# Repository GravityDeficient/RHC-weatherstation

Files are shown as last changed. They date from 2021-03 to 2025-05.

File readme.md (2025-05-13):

# RHC - Weather Station
An open source self contained weather station for remote applications where wifi and power are not available.

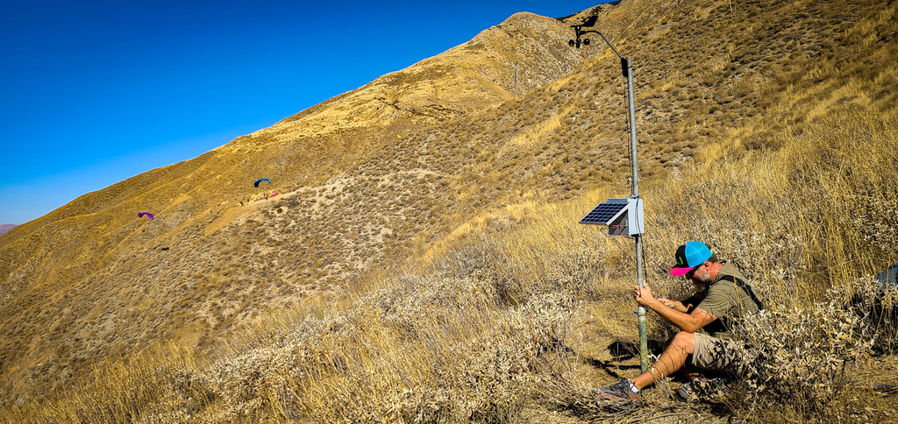
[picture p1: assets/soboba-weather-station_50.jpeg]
Soboba Flight Park Weather Station

### Overview

The weather station is based around the Particle Cloud platform and the latest design uses the Particle.IO Boron LTE CAT-M1 development board for processing and connectivity. 
Additionally a small arduino pro-mini is used as a watchdog to monitor system state and induce a restart if the system is hung. This forces the Particle to reconnect and check in.

Wind observation are taken using a Davis Vantage Pro 6410 anemometer. Temperature, pressure, and humidify can be observed with a BPM280 or BME280 sensor.

Listener software running on a base unit (internet connected Particle Argon) or server application (nodejs) will monitor observations published to particle cloud from the weather station and post the parsed data to Weather Underground and Weather Flow. In the case of the server application we log obervations to a database that serves can be used to generate your own weather graphs without 3rd part services.

- [Recommended BOM](bom.md) 
- [Assembly instructions](assembly.md)
- [RHC-Weatherstation-Listener](https://github.com/GravityDeficient/RHC-Weatherstation-Listener) Reciever applictaion written in NodeJS
- [To-Do](TODO.md)

### Configuration
The weather station uses a simple configuration system that's easy to customize:

1. All configuration settings are in a single file: `config.h`
2. If you're setting up a new installation, copy `config.h.example` to `config.h`
3. Edit the settings in the clearly marked "USER CONFIGURATION" section
4. Make your changes directly in this file - the comments provide guidance on what each setting does
5. Note that `config.h` is in .gitignore, so your custom settings won't be committed

Key settings you might want to customize:
- EVENT_NAME: The name used for publishing data to the Particle Cloud 
- TIMEZONE: Set to your local timezone
- USE_DST: Enable or disable Daylight Saving Time
- CNTS_TO_MPH: Calibration factor for your specific anemometer

Example of the config.h settings:

```c
// Event name for publishing data
// Change this to your own custom event name
#define EVENT_NAME ("my_custom_event")

// Timezone settings
// Modify for your location
#define TIMEZONE (-8)  // Pacific Standard Time

// Daylight Saving Time settings
#define USE_DST (1)    // Enable Daylight Saving Time
#define DST_OFFSET (1) // 1 hour offset for DST

// DST start rule (second Sunday in March for USA)
#define DST_START_MONTH (3)  // March
#define DST_START_WEEK (2)   // Second week
#define DST_START_DOW (0)    // Sunday (0 = Sunday, 1 = Monday, etc.)

// DST end rule (first Sunday in November for USA)
#define DST_END_MONTH (11)   // November
#define DST_END_WEEK (1)     // First week
#define DST_END_DOW (0)      // Sunday

// Wind speed calibration
// Change this for your specific anemometer
#define CNTS_TO_MPH (2.174)  // For Mussel Rock Anemometer
```

After changing the configuration, compile and flash your device to apply the changes.

### Important Notes for Compilation

- **Pro Mini Watchdog**: Before compiling the Boron firmware, you must remove the `station/pro-mini_watchdog.ino` file. This file is for the Arduino Pro Mini watchdog device and should not be included in the Boron compilation.

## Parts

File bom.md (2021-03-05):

### BOM
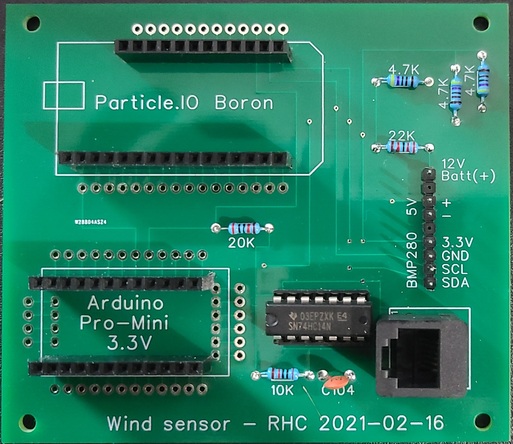
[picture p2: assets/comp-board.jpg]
Assembled Board

#### Hardware Power and Sensors 
1. 20A Solar Charge Controller --[Amazon](https://www.amazon.com/gp/product/B072MMDY4F)
2. ExpertPower 12v 9ah Sealed Lead Acid Battery --[Amazon](https://www.amazon.com/ExpertPower-EXP1290-2-Batteries-BX1300LCD-Replacement/dp/B001NJ3H0C)
3. 10W Solar Panel --[Amazon](https://www.amazon.com/gp/product/B00OZC3X1C/)
4. Cantex 5133712 Electrical Box --[Ebay](https://www.ebay.com/itm/CANTEX-5133712-Electrical-Box-PVC-8-5-8x8-5-8x4-in/383686744477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)
5. Davis Instruments 6410 Anemometer --[Ebay](https://www.ebay.com/itm/Davis-Instruments-6410-Davis-Anemometer-For-Vantage-Pro-Pro2-6152-New/383033311103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)
6. 1/2 NPT Nylon Cable Gland --[Amazon 12pcs](https://www.amazon.com/gp/product/B07ZRH3V59/ref=ppx_yo_dt_b_asin_title_o02_s00?ie=UTF8&psc=1)

##### Optional Sensors
- BMP280 (Preasure, Temperature) --[Amazon](https://www.amazon.com/GY-BMP280-3-3-Precision-Atmospheric-Pressure-Barometric/dp/B087ZRGSC8/)
- BME280 (Pressure, Temperature, Humidity) --[Amazon](https://www.amazon.com/Aideepen-Breakout-Temperature-Precision-Barometric/dp/B07RWCCKJX/)

#### PCB Components
1. Boron LTE CAT-M1 (NorAm) --[Particle.io](https://store.particle.io/products/boron-lte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) 
2. Ardunio Pro-Mini (3.3v) --[Amazon](https://www.amazon.com/gp/product/B01JA58DHM/)
3. PCB
4. 3x 4.7K resisters
5. 1x 22k resister
6. 1x 20k resister
7. 1x 10k resister
8. 1x C104 capacitor (0.1uF Ceramic Capacitor)
9. 1x 74HC14 Schmitt−Trigger
10. 2x 40 Pin 2.54mm Female Pin Header -This is broken up and used in 3 rows of 12 pins and 1 row of 16 pins.
11. 1x 40 Pin 2.54mm Male Pin Header -We only use half part of it. A continuous row of 9 pins works best.
12. 1x RJ11 jack [Digikey](https://www.digikey.com/en/products/detail/molex/0428786218/1643555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)
13. 1x (optional) 14pin dip chip socket

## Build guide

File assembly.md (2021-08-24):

#### Wiring to the wind instrument: 
(Davis Instruments Anemometer and weather vane #6410; about $120 from Amazon and even less on ebay):
  - Anemometer GREEN wire to Boron A4 (Green goes to the wiper on the pot that measures wind direction)
  - Anemometer YELLOW wire to 3.3V  (Red and Yellow are the two ends of the pot that measures direction)
  - Anemometer RED wire to GND  (Red and black are the cup switch - but polarity is IMPORTANT)
  - Anemometer BLACK wire to Pin 1 of the Schmitt trigger (74HC14)
  - Schmitt trigger pin 2 to Boron D3 (interrupt 0)
  - Schmitt trigger pin 14 to 5V and pin 7 to GND
  - Schmitt trigger pin 1 is pulled up to Vcc with a 10K resistor
  - Ceramic "104" cap between Gnd and Schmitt trigger pin 1

#### Anemometer:
  - Red/Black: cup switch (Red to GND)
  - Red/Yellow: The two ends of the direction pot (Yellow to Vcc; 3.3V)
  - Green: The wiper on the direction pot (Green to A4)
  - I currently have the Mussel Rock wind vane set up so that it reads 175.5 when it's exactly aligned with the arm
    (i.e. arm pointing to the West and wind coming from the west.)
  - Davis 6410 Anemometer:  Speed in mph = 2.250 * counts/sec

#### Wiring to the BMP/BME280
This may differ depending on your sensor

|BMP280 | Boron|
|---|---|
|1. Vcc | 3.3V |
|2. GND | GND  |
|3. SCL | D1 (Don't forget 4.7K pull up resistors on both A4 and A5)|
|4. SDA | D0 (Don't forget 4.7K pull up resistors on both A4 and A5)|
|5. CSB | 3.3V to select I2C mode (Not sure this is required as I2C should be default mode)|
|6. SDO | 3.3V to select slave address 0x77|

#### Wiring the Watchdog/Arduino Pro-Mini
|Boron | Arduino |
|---|---|
|A5 | held high (3.3V) with a 20K resistor |
|D2 | Arduino D2 (This is the line that pings the Arduino to let it know all is well still.)|
|Rst | Arduino D3 (This resets the Boron if a ping isn't received for 20 minutes.)|

#### Solar charge controller:
 - Connect the battery, solar panel, then load.  Dicsonnect them in the reverse order
 - On the solar charge controller there's a low-voltage cut-off which defaults to 10.7V.  There's also a "reconnect" threshold
   which defaults to 12.6V.  I reprogrammed the reconnect to occur at 12.4 volts.
 - The system draws just under 40mA from the 12V battery once it's up and running.
   So that should run 175 hours (about one week) on a 7AH gel cell.
 - I measured the current from the panel and found it was only giving me 14mA on an overcast day through the window (with the battery at 12.2V).
   A bit of research suggests that solar panels produce only 10%-25% of their normal output on overcast days, and Low-E windows can reduce
   their output by more than 50%.  I then opened the window (still overcast day) and got it up to 33mA.  By holding it outside the window
   a bit it went up to 40mA (maybe it was in the shadow of the roof overhang).
   When the sun peeked out for a few minutes I took additional readings: 98mA through the window and 160mA not looking through window.
   More solar panel results: bright sunny winter day - 305mA through bedroom window; 430mA without window (with battery already at 3.8V).
 - ExpertPower recommended settings for EXP1233 battery:  Type B01 (14.4V boost, absorption, equalization); Float 13.8V; Discharge stop 11.0V.

#### Battery voltage monitoring:
 - Use 22K and 4.7K resistors to make a voltage divider (12V will map to 2.11V);  22K on top (to +side of gel cell) and 4.7K on bottom (to Gnd).
   Center of divider connects to input A5 of the Boron.
   
**IMPORTANT NOTE:** the particular charge controller I got for our wind station has positive common between the solar panel input, battery input, and load.
     This would normally make it impossible to read battery voltage from an analog input on the Boron.  But as luck would have it it the
     battery and USB output (that I use to power the Boron) share a common ground.  This makes it possible.  DO NOT do this if the
     battery and Boron don't share a common ground.

#### Solar Notes 
(Electron -legacy) looks like this settles into about 43mA at 5V; but frequently goes up to 160mA. Apparently it can run more than 1A during a publish.

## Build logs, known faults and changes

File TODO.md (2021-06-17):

##To-do:
- [Feature] Perhaps we should register a function using Particle.function() that allows you to change the update rate and start/stop times.
- [Electron bug] Figure out why we get a big jump in wind gust when I have a connection outage.
- [Feature] Encode mph with alpha-numerics and do fractions of MPH. Using upper-case letters and numbers we can encode 0-129 mph in 0.1 mph increments (using 2 chars).
   If we used the printable ASCII characters (32-126) we could encode speed in 1/2 MPH increments with a single character (from 0 to 47 mph).
   Two characters would allow us to describe direction to about 1/25th of a degree.
- [Feature] Maybe we should send previous data with each event.  This could allow us to fill in gaps, or to get greater granularity even if
   we don't increase the update rate.
- [Electron bug] Figure out whether the failed updates are happening on the Electron or Photon side (by watching the logs).
- [Feature] Consider having it sleep at night (lower current draw and potentially some data savings)
    https://docs.particle.io/reference/firmware/electron/#sleep-sleep-
    Probably should have sleep from sunset to sun-up.  Figure out what those hours are each month.
- [Electron bug] Check to see if it's stuck trying to connect and maybe do a reset:
      Look at SYSTEM_MODE(SEMI_AUTOMATIC) and SYSTEM_THREAD(ENABLED) to stay ontop of the background task
      and handle reconnects myself rather than letting some "obscure" magic happen.
      User can call reset() to force a full reset.
      *** With SYSTEM_THREAD(ENABLED) or Software Timers you can have your own code run to check
          Particle.connected() and do whatever you want when this returns false.
      Also look at: ApplicationWatchdog()
      Discussion here: https://community.particle.io/t/using-lots-of-data-to-connect/31292/8
- [Cleanup] Share the PCB design on a site like pcbway where they can be ordered
- [Boron Update] On Gen3 devices (and since DeviceOS 0.5.3) it is no longer necessary to set pinMode().  Pine Mtn station had an issue with bad readings on A4. Particle Support believes that setting pinmode() could be the culprit.  "You do not need to set the pinMode() to read an analog value using analogRead as the pin will automatically be set to the correct mode when analogRead is called." https://docs.particle.io/cards/firmware/input-output/analogread-adc/

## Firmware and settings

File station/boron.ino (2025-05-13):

//===============================================================================================================
// This code for the Particle Boron publishes an event with wind data every 5 minutes 24 hrs/day.
// It publishes on each whole 5 minute interval (i.e. 10:00, 10:05; 10:10...).
// The Boron uses the cell phone network, so it's important to keep the data usage very low.
//===============================================================================================================
// Include configuration
#include "config.h"

#include <math.h>
#include <stdlib.h>
#include <time.h>
#include <Wire.h>
#include <SPI.h>
#include <Adafruit_BME280.h>
#include <Adafruit_BMP280.h>


#define R2D (57.2958)

volatile int counter;
int publish_min;  // Publish an event the first time we see we're at this minute.
int first_event;
float gust;
float total_x, total_y;
int led;
int wind_cntr;
int last_wind_cntr;
int loop_counter;
int led_on = 0;
int last_hr = 0;
unsigned long time_in_secs;
unsigned long last_time_in_secs;
unsigned long last_gust_time_in_secs;
unsigned long previousMillis = 0;
const long interval = 10000;

void publish_wind_event(float dt);
int is_dst(int year, int month, int day);
void click(void);
float get_battery_voltage(void);

SerialLogHandler logHandler; // Enable Serial Logging
ApplicationWatchdog wd(3600000, System.reset);  // Set the watchdog to reboot the Boron if it doesn't get pinged for 1 hour

//-3- System remote reset variables --We use a particle cloud function to maintain a reset
#define DELAY_BEFORE_RESET 2000
unsigned int resetDelayMillis = DELAY_BEFORE_RESET;
unsigned long resetSync = millis();
bool resetFlag = false;

//-3- BMP/BME280 sensor setup
bool bme280_present;
Adafruit_BME280 bme;
bool bmp280_present;
Adafruit_BMP280 bmp;

//@@ setup===============================================================================================================
//=======================================================================================================================
void setup()
{
    int i;
    int hr, min, sec;

    delay(10);  //Make sure sensor had enough time to turn on. BME280 requires 2ms to start up.

    //Calling .begin() causes the settings to be loaded
    bme280_present = bme.begin();
    if(!bmp280_present) {
        bmp280_present = bmp.begin();
    }

    serialConnectBanner();

    led = 0;
    pinMode(A5, INPUT);  // This will monitor the gel-cell battery voltage.
    pinMode(A4, INPUT);  // Reads the wind direction pot.
    pinMode(D2, OUTPUT);  // This will ping the external watchdog
    pinMode(D7, OUTPUT);  // controls LED
    pinMode(D3, INPUT);   // This reads the input from the wind cups

    digitalWrite(D2, LOW);  // Trigger the external watchdog to let it know we're alive
    delay(1);
    digitalWrite(D2, HIGH);

    attachInterrupt(D3, click, RISING);      // Call click() when interrupt 0 (digital pin 2) rises (this is the wind cups spinning)

    setTimeZone(); // Set the timezone from the provided const TIMEZONE offset

    counter = 0;
    gust = 0.0;
    loop_counter = 0;
    last_wind_cntr = 0;
    total_x = 0;
    total_y = 0;

    hr = Time.hour();
    min = Time.minute();
    sec = Time.second();
    last_time_in_secs = hr*3600 + min*60 + sec;
    last_gust_time_in_secs = last_time_in_secs;

    for(i=1; i<=12; i++)
    {
        publish_min = 5*i;
        if (publish_min > min) break;
    }
    publish_min += 5;  // for the first event we'll go up to an extra 5 minutes just in case we're very close to an edge.
    if (publish_min >= 60) publish_min -= 60;

    first_event = 1;

    wd.checkin(); // ping the watchdog after the connection is made - in case it took a while.

    //  Remote Reset Particle Function
    Particle.function("reset", cloudResetFunction);
}

//@@ loop================================================================================================================
// We'll loop every 10 seconds and check the wind speed and direction.  We'll do this for 5 minutes, and then publish an
// event with the average wind speed, the wind gust (highest 10 second reading), and the average wind direction.
//=======================================================================================================================
void loop()
{
    int dir;
    float speed;
    float x, y;
    float angle, dt;
    int hr, min, sec;
    unsigned long currentMillis = millis();

    serialConnectBanner();

    if (currentMillis - previousMillis >= interval) { // Take wind speed and direction readings every 10 seconds
        previousMillis = currentMillis;
        hr = Time.hour();
        min = Time.minute();
        sec = Time.second();
        time_in_secs = hr*3600 + min*60 + sec;

        if (hr < last_hr) {
            Particle.syncTime();  // Sync the clock with the cloud every day at midnight.
            setTimeZone(); // Reset the timezone every day to allow DST adjustments
        }
        last_hr = hr; // Note that it automatically syncs when it connects to the cloud.

        Log.info("Time: %d:%d", hr, min);

        dir = analogRead(A4);

        angle = 15.0 + (345.0/4095.0) * (float)(dir);  // NOTE: we use 345 rather than 360 because there's a roughly 15 degree dead-spot
        // Nominally the arm is supposed to be aimed true North, but there's a dead-spot about 0-15 deg.

        x = cos(angle/R2D);
        y = sin(angle/R2D);
        total_x += x;
        total_y += y;

        wind_cntr = counter; // this keeps the total count for the event publish interval (currently 8 minutes)

        //-3- it looks like this is the problem.  If we lose connection the time could end up being much more than 10 seconds.
        dt = (float)(time_in_secs - last_gust_time_in_secs);
        speed = CNTS_TO_MPH * (float)(wind_cntr - last_wind_cntr) / dt;  // this gives wind speed in mph for the Davis 6410 anemometer
        if (speed > gust) gust = speed;
        last_wind_cntr = wind_cntr;
        loop_counter += 1;
        last_gust_time_in_secs = time_in_secs;
        Log.info("Wind Counter: %d Dir: %d", (int)wind_cntr, (int)angle);

        if (led_on == 1)
        {
            digitalWrite(D7, LOW);
            led_on = 0;
        }
        else
        {
            digitalWrite(D7, HIGH);
            led_on = 1;
        }

        if (min == publish_min)
        {
            publish_min += 5;
            if (publish_min >= 60) publish_min -= 60;
            wd.checkin();

            digitalWrite(D2, LOW);  // Trigger the external watchdog to let it know we're still alive
            delay(1);
            digitalWrite(D2, HIGH);

            dt = (float)(time_in_secs-last_time_in_secs);
            Log.info("Time in seconds: %d", dt);
            last_time_in_secs = time_in_secs;
            /* if (hr >= 8 && hr < 20)  We publish wind events 24 hrs/day now since Particle up'd the monthly data from 1MB to 3MB */
            publish_wind_event(dt);
            counter = 0;
            last_wind_cntr = 0;
            loop_counter = 0;
            gust = 0;
            total_x = 0;
            total_y = 0;
        }
    }

    //  Remote Reset Function
    if ((resetFlag) && (millis() - resetSync >=  resetDelayMillis)) {
        Log.info("Remote Reset Initiated");
        Particle.publish("Debug", "Remote Reset Initiated", 300, PRIVATE);
        System.reset();
    }
}

void publish_wind_event(float dt)
{
    // dt is the number of seconds we've been accumulating wind data for since the last publish.
    char buf[300];
    float speed;
    int wind_speed;
    int wind_gust;
    int wind_dir;
    float dir;
    float temp, pressure, humidity_raw;
    int itemp, ipressure, humidity, voltage;

    // Use global "wind_cntr" as the total cup turns for the publish interval
    // Use global "gust" as the max 10 second cup speed (in rotations/second)
    // Use globals "total_x" and "total_y" to compute avg wind direction.

    speed = CNTS_TO_MPH * (float)wind_cntr / dt;
    wind_speed = (int)(speed + 0.5);
    wind_gust = (int)(gust + 0.5);
    dir = R2D * atan2(total_y, total_x);
    wind_dir = (int)(dir + 0.5);
    if (wind_dir >= 360) wind_dir -= 360;
    if (wind_dir < 0) wind_dir += 360;

    itemp = 0;
    ipressure = 0;
    humidity = 0;
    if (bme280_present) {
        // Read sensor values and convert units
        temp = (bme.readTemperature() * 9/5) + 32;    // Read Temperature in C, convert to F
        itemp = (int)(temp + 0.5);                    // Round to nearest integer F
        pressure = bme.readPressure() / 100;          // Read Pressure in Pa, convert to mBar
        ipressure = (int)(pressure * 10.0 + 0.5);     // Store as integer (tenths of mBar)
        humidity_raw = bme.readHumidity();            // Relative humidity percentage as float
        humidity = (int)(humidity_raw + 0.5);         // Round to nearest integer

        // Log both raw sensor values and integer values used for transmission
        Log.info("Sensor readings - BME280:");
        Log.info("  Temperature: %d F (raw: %.1f F)", itemp, temp);
        Log.info("  Pressure: %d.%d mBar (raw: %.2f mBar)", ipressure/10, ipressure%10, pressure);
        Log.info("  Humidity: %d%% (raw: %.1f%%)", humidity, humidity_raw);

    } else if (bmp280_present) {
        // Read sensor values and convert units
        temp = (bmp.readTemperature() * 9/5) + 32;    // Read Temperature in C, convert to F
        itemp = (int)(temp + 0.5);                    // Round to nearest integer F
        pressure = bmp.readPressure() / 100;          // Read Pressure in Pa, convert to mBar
        ipressure = (int)(pressure * 10.0 + 0.5);     // Store as integer (tenths of mBar)

        // Log both raw sensor values and integer values used for transmission
        Log.info("Sensor readings - BMP280:");
        Log.info("  Temperature: %d F (raw: %.1f F)", itemp, temp);
        Log.info("  Pressure: %d.%d mBar (raw: %.2f mBar)", ipressure/10, ipressure%10, pressure);

    }

    voltage = get_battery_voltage();

    if (bme280_present) {
        sprintf(buf, "%02d%02d%03d%03d%05d%03d%02d%1d", wind_speed, wind_gust, wind_dir, itemp, ipressure, humidity, (int)voltage, first_event);
    } else if (bmp280_present) {
        sprintf(buf, "%02d%02d%03d%03d%05d%02d%1d", wind_speed, wind_gust, wind_dir, itemp, ipressure, (int)voltage, first_event);
    } else {
        sprintf(buf, "%02d%02d%03d%02d%1d", wind_speed, wind_gust, wind_dir, (int)voltage, first_event);
    }


    Log.info("Event: %s", EVENT_NAME);
    Log.info("Publish: %s", buf);
    Particle.publish(EVENT_NAME, buf, PRIVATE);

    first_event = 0;
}

// ============================================================================
// Interupt routine.  This gets called once for each rotation of the wind cups.
// ============================================================================
void click()
{
    counter++;
}

// ============================================================================
// This function reads the battery voltage on pin A5 and maps it to a
// scale of 0-99 (which maps to 5.0-14.9 volts).  That way we can post it with
// the rest of the event data as 2 digits.
// Note: The pin delivers a value of 0-4095 which represents 0 - 3.3V
//       But the input battery voltage goes through a voltage divider that
//       uses a 22K resistor over a 4.7K resistor.
// ============================================================================
float get_battery_voltage()
{
    int voltage;
    float batt_voltage;

    voltage = analogRead(A5);

    // divide by 4096 and multiply by 3.3 to get the voltage on the pin.
    // Then multiply by 5.68 to get the battery voltage rather than the
    // voltage coming out of the voltage divider.

    batt_voltage = (float)voltage / 218.52;
    Log.info("Batt: %d", batt_voltage);

    // We want to express the voltage as two digits so we'll subtract 5 volts and
    // then divide by 10.  This way 5-14.9 Volts becomes 0-99

    batt_voltage -= 5.0;
    if (batt_voltage < 0.0) batt_voltage = 0.0;

    batt_voltage *= 10;
    if (batt_voltage > 99) batt_voltage = 99;

    return(batt_voltage);
}

// ============================================================================
// Return 1 if we're currently observing Daylight Saving Time.
// DST dates are calculated based on the configuration in config.h,
// which can be overridden by settings in config.local.h.
// By default, DST starts on the second Sunday in March and ends on the first
// Sunday in November, but this can be customized in the config files.
// See config.local.h.example for an example of how to override these settings.
// ============================================================================
int is_dst(int year, int month, int day)
{
    #if USE_DST
    // DST start calculation
    struct tm tmStart = {0};
    tmStart.tm_year = year - 1900;
    tmStart.tm_mon = DST_START_MONTH - 1;
    tmStart.tm_mday = 1;
    time_t tStart = mktime(&tmStart);
    // Adjust to the correct Sunday
    struct tm *startTime = localtime(&tStart);
    int startWeekday = startTime->tm_wday; // 0 = Sunday, 1 = Monday, etc.
    int dstStartDay = (7 - startWeekday) % 7 + 1 + (DST_START_WEEK - 1) * 7;

    // DST end calculation
    struct tm tmEnd = {0};
    tmEnd.tm_year = year - 1900;
    tmEnd.tm_mon = DST_END_MONTH - 1;
    tmEnd.tm_mday = 1;
    time_t tEnd = mktime(&tmEnd);
    // Adjust to the correct Sunday
    struct tm *endTime = localtime(&tEnd);
    int endWeekday = endTime->tm_wday; // 0 = Sunday, 1 = Monday, etc.
    int dstEndDay = (7 - endWeekday) % 7 + 1 + (DST_END_WEEK - 1) * 7;

    // Check if current date is within DST
    if (month > DST_START_MONTH && month < DST_END_MONTH) {
        return 1; // Clearly within DST period
    }
    if (month == DST_START_MONTH && day >= dstStartDay) {
        return 1; // During start month, on or after DST start day
    }
    if (month == DST_END_MONTH && day < dstEndDay) {
        return 1; // During end month, before DST end day
    }
    #endif
    return 0; // Not in DST
}

//****************************************************************************//
//
//  Utility functions
//
//****************************************************************************//

void setTimeZone() {
    int dst_status = is_dst(Time.year(), Time.month(), Time.day());
    if (dst_status) Time.zone(TIMEZONE);
    else Time.zone(TIMEZONE - DST_OFFSET);
}

//  Remote Reset Function
int cloudResetFunction(String command) {
    resetFlag = true;
    resetSync = millis();
    return 0;
}

//****************************************************************************//
//  Serial connection banner -
//      Logs information about currently the running firmware on serial connect
//****************************************************************************//
void serialConnectBanner() {
    static int serial_state;

    // on serial connect we output the data on the running firmware
    if(Serial.isConnected() && serial_state == 0) {

        Log.info("Device ID: %s", (const char*)System.deviceID());
        Log.info("System Version: %s", System.version().c_str());
        if(bme280_present) Log.info("BME280_PRESENT: TRUE");
            else Log.info("BME280_PRESENT: FALSE");
        if(bmp280_present) Log.info("BMP280_PRESENT: TRUE");
            else Log.info("BMP280_PRESENT: FALSE");
        Log.info("EVENT_NAME: %s", EVENT_NAME);
        Log.info("UpTime: %d", System.uptime() / 60);

        serial_state = 1;
    }

    if(!Serial.isConnected()) {
        serial_state = 0;
    }
}

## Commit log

2019-03-02 Added reboot code
    If the device is not pinged for 1 hour we reboot.
    On reboot we publish a special event code.
    [Electron_side.ino]
2019-03-03 External Watchdog + MAX6675 temperature sensor
    Added code to have pin B0 ping the external watchdog
    Added support for MAX6675 temperature sensor
2019-03-03 BMP280 temp sensor + second photon reciever event
2019-03-04 removed delay 10000, and added serial logging +
    - Added variable for event name and first event name
    - Defined temperature and pressure to be zero when sensor is not present.
    - Moved BMP280 to its own .h library file.
    - Change serial.print to serial logging. With logging enabled we can see more details on the connection state.
    - Removed the delay 10000 in favor or a timer so we dont need to hold up the entire app. This allows logging to work even between measurements.
2021-03-05 added gerber files, and updated bom with rj11 jack
    [drill_file.drl]
2021-11-30 Fixed Log.info pressure typos
    [boron.ino]
2025-04-23 Fix: Correct DST calculation using <time.h>
    Refactors the `is_dst()` function to accurately calculate Daylight Saving Time start and end dates based on the configuration in `config.h`.
    The previous implementation relied on hardcoded day numbers, causing incorrect DST transitions in most years.
    This commit updates `is_dst()` to:
    - Use `<time.h>` structures (`struct tm`) and functions (`mktime`, `localtime`) to determine the correct weekday for date calculations.
    - Calculate the Nth Sunday of the `DST_START_MONTH` and `DST_END_MONTH` based on `DST_START_WEEK` and `DST_END_WEEK` from the configuration.
    - Accept year, month, and day parameters for improved accuracy and testability.
    Updates th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
    [boron.ino]
2025-04-25 Fix config to ensure custom settings are applied
    Replace conditional configuration system with example-based approach
    The previous approach using conditional inclusion of config.local.h had several issues:
    - The inclusion using #ifdef CONFIG_LOCAL_H before including the file created a circular dependency
    - Custom EVENT_NAME values weren't being recognized, with the system falling back to a hard-coded value
    - Users had to remember to define CONFIG_LOCAL_H before the content, causing confusion
    The new approach:
    - Uses a single config.h file with a corresponding config.h.example template
    - Adds config.h to .gitignore so users' custom settings aren't committed
    - Clearly marks the "USER CONFIGU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
    [boron.ino, pro-mini_watchdog.ino]
2025-04-28 Improve sensor logging w raw and processed values
